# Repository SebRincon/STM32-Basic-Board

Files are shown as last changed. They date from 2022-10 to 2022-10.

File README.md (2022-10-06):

### STM32-Basic-Board

Basic STM32 Board with some basic interface and programmed in C.

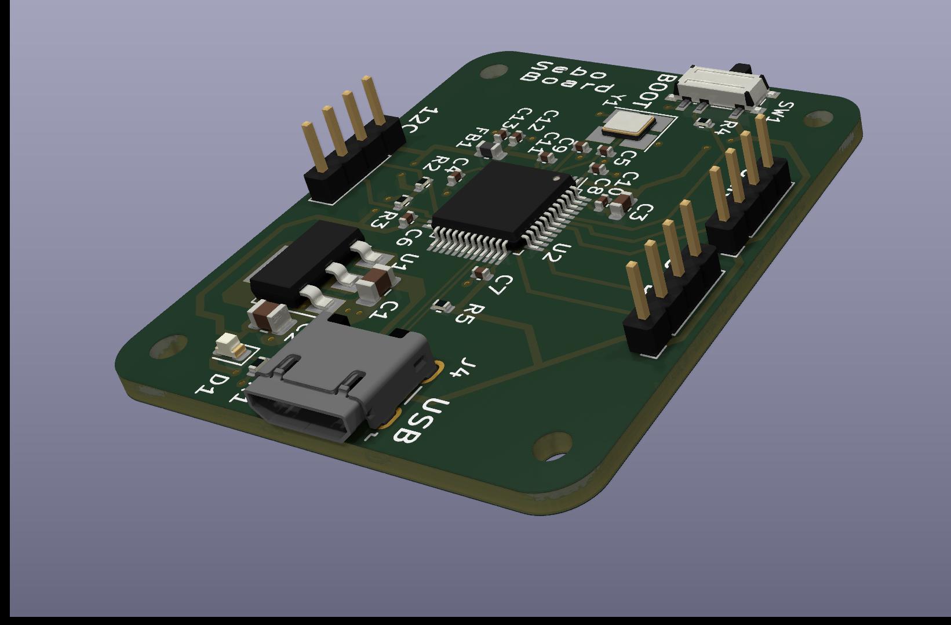
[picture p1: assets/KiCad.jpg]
pcb


PCB Layout                 |        Schematic
:-------------------------:|:-------------------------:
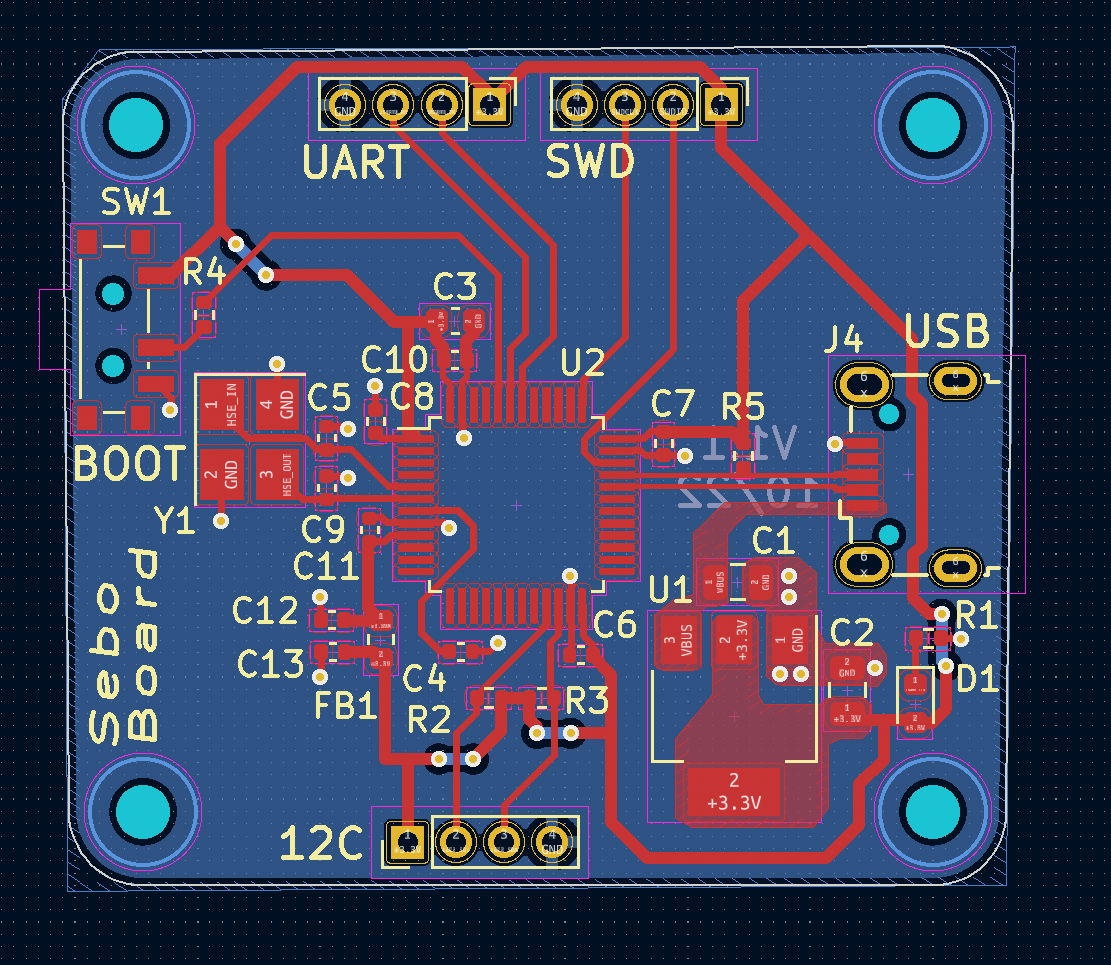
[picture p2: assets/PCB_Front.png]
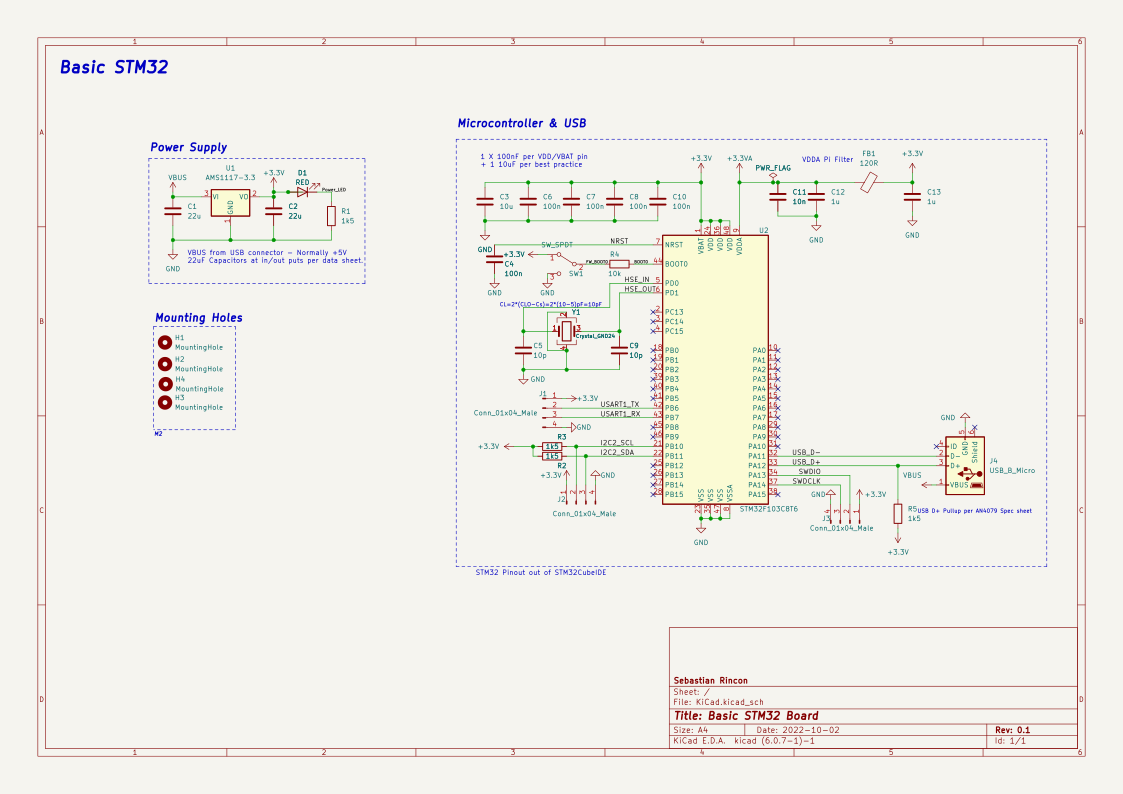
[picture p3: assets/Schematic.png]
  |  

## Missing Assets Locations
[USB Micro](https://www.we-online.com/catalog/en/COM_MICRO_SMT_TYPE_B_HORIZONTAL_HIGH_CURRENT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)

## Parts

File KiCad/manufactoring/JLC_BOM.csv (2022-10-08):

Designator | Comment | Footprint | JLCPCB Part #
C1, C2, | 22u | Capacitor_SMD:C_0805_2012Metric | C140362
C3, | 10u | Capacitor_SMD:C_0603_1608Metric | C19702
C4, C6, C7, C8, C10, | 100n | Capacitor_SMD:C_0402_1005Metric | C131394
C5, C9, | 10p | Capacitor_SMD:C_0402_1005Metric | C469620
C11, | 10n | Capacitor_SMD:C_0402_1005Metric | C525224
C12, C13, | 1u | Capacitor_SMD:C_0402_1005Metric | C29266
D1, | RED | LED_SMD:LED_0603_1608Metric | C389517
FB1, | 120R | Inductor_SMD:L_0603_1608Metric | C42102
J1, J2, J3, | Conn_01x04_Male | Connector_PinHeader_2.00mm:PinHeader_1x04_P2.00mm_Vertical | C541858
J4, | USB_B_Micro | Connector_USB:USB_Micro-B_Wuerth_629105150521 | C132560
R1, R2, R3, R5, | 1k5 | Resistor_SMD:R_0402_1005Metric | C25867
R4, | 10k | Resistor_SMD:R_0402_1005Metric | C269674
SW1, | SW_SPDT | Button_Switch_SMD:SW_SPDT_PCM12 | C431541
U1, | AMS1117-3.3 | Package_TO_SOT_SMD:SOT-223-3_TabPin2 | C6186
U2, | STM32F103C8T6 | Package_QFP:LQFP-48_7x7mm_P0.5mm | C8734
Y1, | Crystal_GND24 | Crystal:Crystal_SMD_3225-4Pin_3.2x2.5mm_HandSoldering | C518160

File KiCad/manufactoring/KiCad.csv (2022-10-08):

Designator | Qnty | Value | Cmp name | Footprint | Description | Vendor | JLCPCB Part #
C1, C2, | 2 | 22u | C | Capacitor_SMD:C_0805_2012Metric | Unpolarized capacitor |  | C140362
C3, | 1 | 10u | C | Capacitor_SMD:C_0603_1608Metric | Unpolarized capacitor |  | C19702
C4, C6, C7, C8, C10, | 5 | 100n | C | Capacitor_SMD:C_0402_1005Metric | Unpolarized capacitor |  | C131394
C5, C9, | 2 | 10p | C | Capacitor_SMD:C_0402_1005Metric | Unpolarized capacitor |  | C469620
C11, | 1 | 10n | C | Capacitor_SMD:C_0402_1005Metric | Unpolarized capacitor |  | C525224
C12, C13, | 2 | 1u | C | Capacitor_SMD:C_0402_1005Metric | Unpolarized capacitor |  | C29266
D1, | 1 | RED | LED | LED_SMD:LED_0603_1608Metric | Light emitting diode |  | C389517
FB1, | 1 | 120R | FerriteBead | Inductor_SMD:L_0603_1608Metric | Ferrite bead |  | C42102
J1, J2, J3, | 3 | Conn_01x04_Male | Conn_01x04_Male | Connector_PinHeader_2.00mm:PinHeader_1x04_P2.00mm_Vertical | Generic connector, single row, 01x04, |  | C124378
J4, | 1 | USB_B_Micro | USB_B_Micro | Connector_USB:USB_Micro-B_Wuerth_629105150521 | USB Micro Type B connector |  | C132560
R1, R2, R3, R5, | 4 | 1k5 | R | Resistor_SMD:R_0402_1005Metric | Resistor |  | C25867
R4, | 1 | 10k | R | Resistor_SMD:R_0402_1005Metric | Resistor |  | C269674
SW1, | 1 | SW_SPDT | SW_SPDT | Button_Switch_SMD:SW_SPDT_PCM12 | Switch, single pole double throw |  | C431541
U1, | 1 | AMS1117-3.3 | AMS1117-3.3 | Package_TO_SOT_SMD:SOT-223-3_TabPin2 | 1A Low Dropout regulator |  | C6186
U2, | 1 | STM32F103C8T6 | STM32F103C8Tx | Package_QFP:LQFP-48_7x7mm_P0.5mm | ARM Cortex-M3 MCU |  | C8734
Y1, | 1 | Crystal_GND24 | Crystal_GND24 | Crystal:Crystal_SMD_3225-4Pin_3.2x2.5mm_HandSoldering | Four pin crystal, GND on pins 2 and 4 |  | C518160
Source: | /Users/sebastian/Developer/Circuits/STM32 Basic Board/KiCad/KiCad.kicad_sch
Date: | Wednesday, October 05, 2022 at 09:31:03 PM
Tool: | Eeschema (6.0.7-1)-1
Generator: | /Applications/KiCad/KiCad.app/Contents/SharedSupport/plugins/bom_csv_grouped_by_value_with_fp.py
Component Count: | 32

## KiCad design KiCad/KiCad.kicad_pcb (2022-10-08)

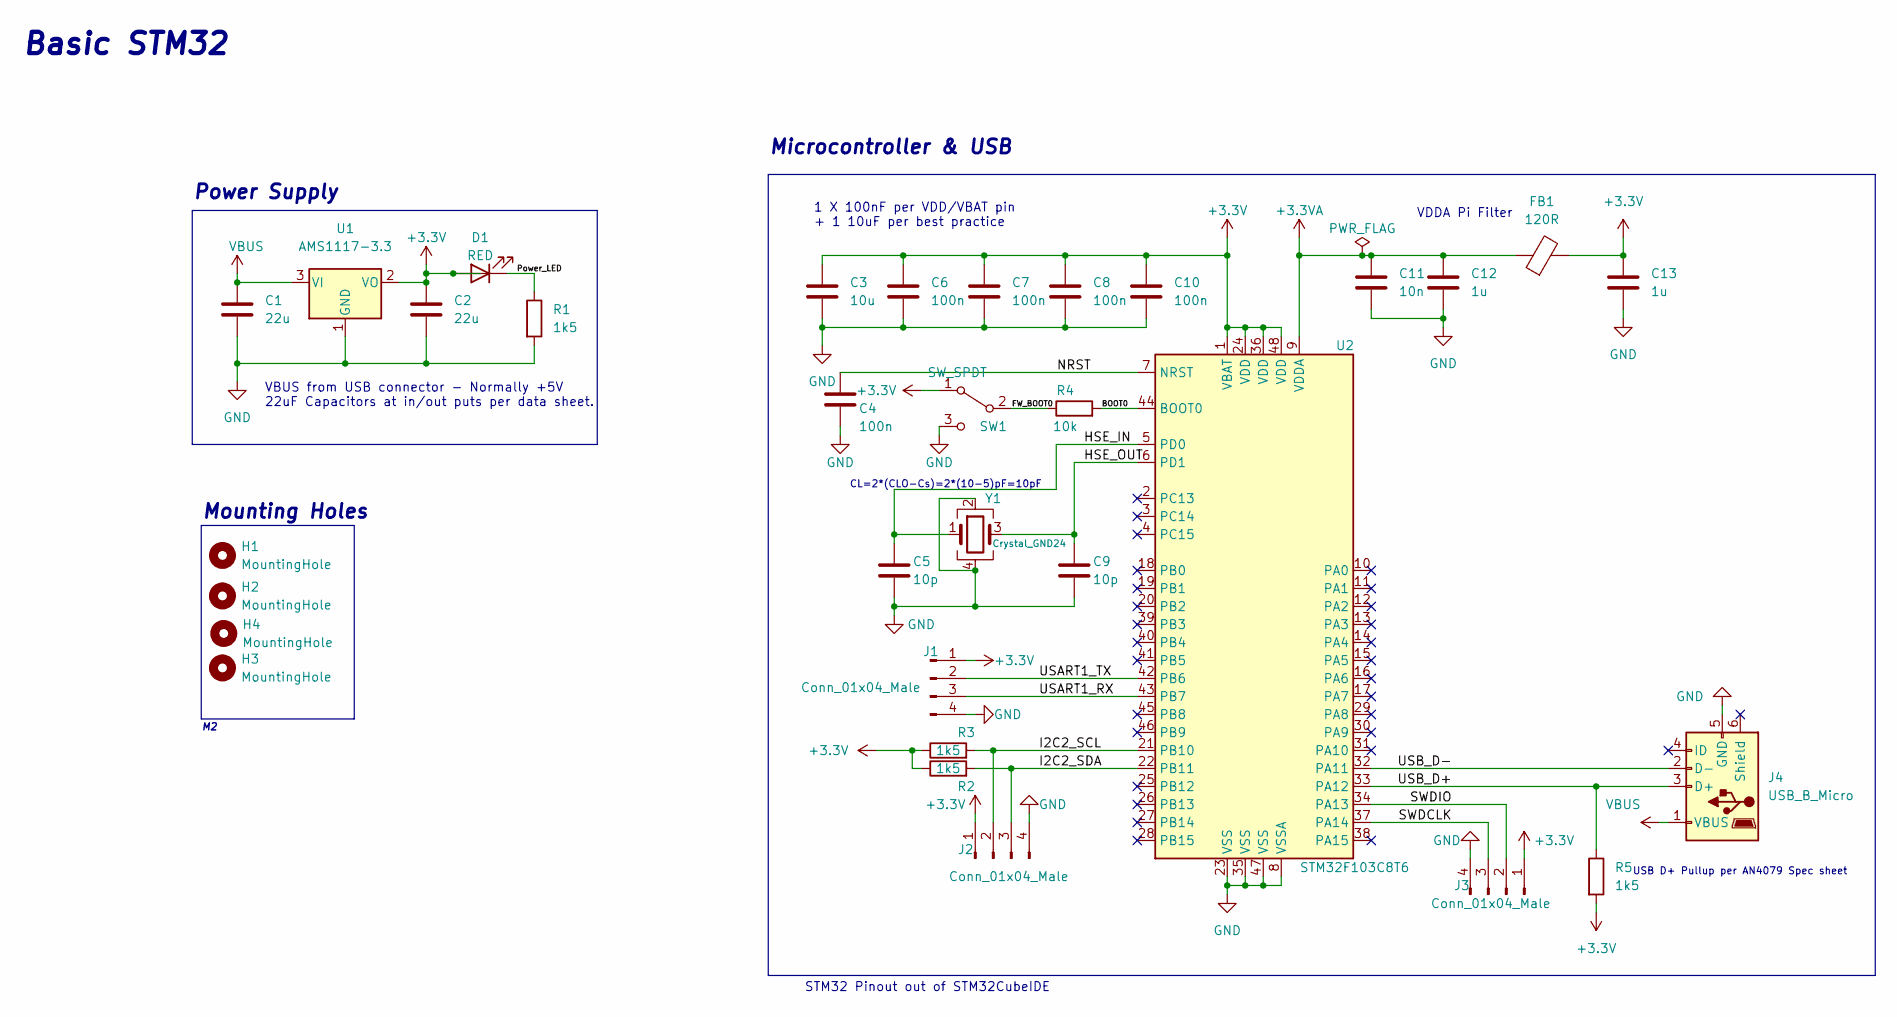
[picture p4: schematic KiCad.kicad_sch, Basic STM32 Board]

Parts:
C1, C2: 22u; C_0805_2012Metric
C3: 10u; C_0603_1608Metric
C4, C6, C7, C8, C10: 100n; C_0402_1005Metric
C5, C9: 10p; C_0402_1005Metric
C11: 10n; C_0402_1005Metric
C12, C13: 1u; C_0402_1005Metric
D1: RED; LED_0603_1608Metric
FB1: 120R; L_0603_1608Metric
H1, H2, H3, H4: MountingHole; MountingHole_2.2mm_M2
J1, J2, J3: Conn_01x04_Male; PinHeader_1x04_P2.00mm_Vertical
J4: USB_B_Micro; USB_Micro-B_Molex_47346-0001
R1, R2, R3, R5: 1k5; R_0402_1005Metric
R4: 10k; R_0402_1005Metric
SW1: SW_SPDT; SW_SPDT_PCM12
U1: AMS1117-3.3; SOT-223-3_TabPin2
U2: STM32F103C8T6; LQFP-48_7x7mm_P0.5mm
Y1: Crystal_GND24; Crystal_SMD_3225-4Pin_3.2x2.5mm

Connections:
+3.3V: C2.1, C3.1, C6.1, C7.1, C8.1, C10.1, C13.1, D1.2 (A), FB1.2, J1.1, J2.1, J3.1, R2.1, R3.1, R5.2, SW1.1 (A), U1.2 (VO), U2.1 (VBAT), U2.24 (VDD), U2.36 (VDD), U2.48 (VDD)
+3.3VA: C11.1, C12.1, FB1.1, U2.9 (VDDA)
/BOOT0: R4.2, U2.44 (BOOT0)
/FW_BOOT0: R4.1, SW1.2 (B)
/HSE_IN: C5.1, U2.5 (PD0), Y1.1
/HSE_OUT: C9.1, U2.6 (PD1), Y1.3
/I2C2_SCL: J2.2, R2.2, U2.21 (PB10)
/I2C2_SDA: J2.3, R3.2, U2.22 (PB11)
/NRST: C4.1, U2.7 (NRST)
/Power_LED: D1.1 (K), R1.1
/SWDCLK: J3.3, U2.37 (PA14)
/SWDIO: J3.2, U2.34 (PA13)
/USART1_RX: J1.3, U2.43 (PB7)
/USART1_TX: J1.2, U2.42 (PB6)
/USB_D+: J4.3 (D+), R5.1, U2.33 (PA12)
/USB_D-: J4.2 (D-), U2.32 (PA11)
GND: C1.2, C2.2, C3.2, C4.2, C5.2, C6.2, C7.2, C8.2, C9.2, C10.2, C11.2, C12.2, C13.2, J1.4, J2.4, J3.4, J4.5 (GND), R1.2, SW1.3 (C), U1.1 (GND), U2.8 (VSSA), U2.23 (VSS), U2.35 (VSS), U2.47 (VSS), Y1.2, Y1.4
VBUS: C1.1, J4.1 (VBUS), U1.3 (VI)

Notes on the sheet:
Microcontroller & USB
VDDA Pi Filter
Mounting Holes
VBUS from USB connector - Normally +5V 22uF Capacitors at in/out puts per data sheet.
STM32 Pinout out of STM32CubeIDE
Basic STM32
1 X 100nF per VDD/VBAT pin + 1 10uF per best practice
CL=2*(CLO-Cs)=2*(10-5)pF=10pF
Power Supply
USB D+ Pullup per AN4079 Spec sheet

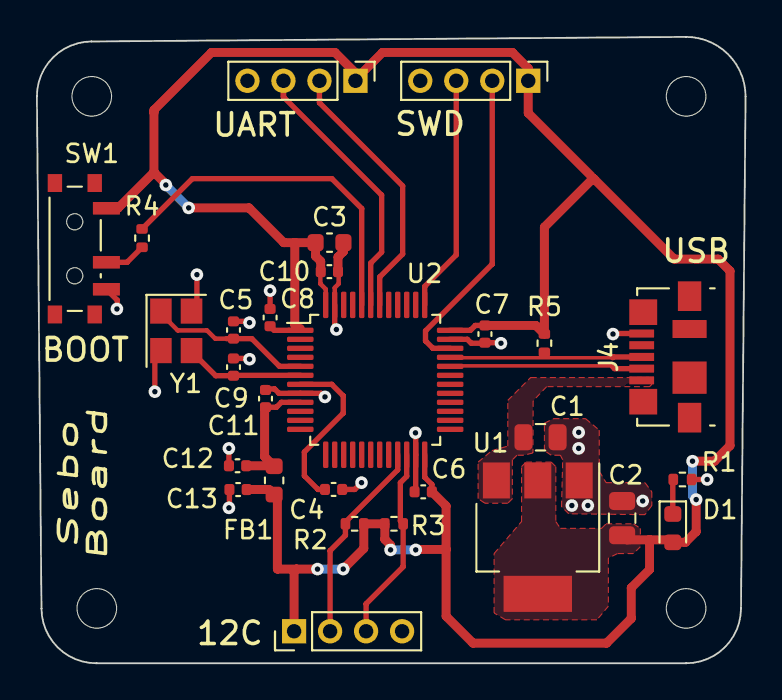
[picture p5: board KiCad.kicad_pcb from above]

Board: 2 copper layers, 39.4 x 34.8 mm, 32 parts (0 on the bottom side), 18 nets.

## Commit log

2022-10-03 Inital Commit
    [KiCad.kicad_sch]
2022-10-03 Added UART & SPI Support pinout
    [KiCad.kicad_sch]
2022-10-03 Added annotation to schematic
    [KiCad.kicad_sch]
2022-10-03 Added Footprints
    [KiCad.kicad_sch]
2022-10-05 Setup the basics for a common PCB
    [KiCad.kicad_pcb]
2022-10-05 Routed STM32 & Various Important components
    Routed the Crystal as well as the Capacitors
    [KiCad.kicad_pcb]
2022-10-05 Swapped switch footprint
    [KiCad.kicad_pcb]
2022-10-05 Fixed route line bugs & routed pheriphials
    [KiCad.kicad_pcb, KiCad.kicad_sch]
2022-10-05 Routed power supply components
    [KiCad.kicad_pcb]
2022-10-05 Added Mounting holes and arranged board outline
    [KiCad.kicad_pcb, KiCad.kicad_sch]
2022-10-06 Routed the sensitive components
    [KiCad.kicad_pcb]
2022-10-06 Routed Pinout Connectors & other signal pins
    [KiCad.kicad_pcb]
2022-10-06 Finished Power Routing
    [KiCad.kicad_pcb]
2022-10-06 Fixed some design bugs and added board title
    [KiCad.kicad_pcb, KiCad.kicad_sch]
2022-10-06 Generated BOM Files
    [KiCad.csv]
2022-10-06 Generated Gerbers
    [KiCad-B_Cu.gbr, KiCad-B_Mask.gbr, KiCad-B_Paste.gbr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]
2022-10-06 Included completed 3D View of board
2022-10-08 Sourced parts & Changed some components
    [KiCad.csv, KiCad.kicad_pcb, KiCad.kicad_sch]
2022-10-08 Recreated the gerbers
    [KiCad-B_Cu.gbr, KiCad-B_Mask.gbr, KiCad-B_Paste.gbr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]
2022-10-08 Remade the BOM & CPL for JLCPCB
    [JLC_BOM.csv, KiCad.csv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]
